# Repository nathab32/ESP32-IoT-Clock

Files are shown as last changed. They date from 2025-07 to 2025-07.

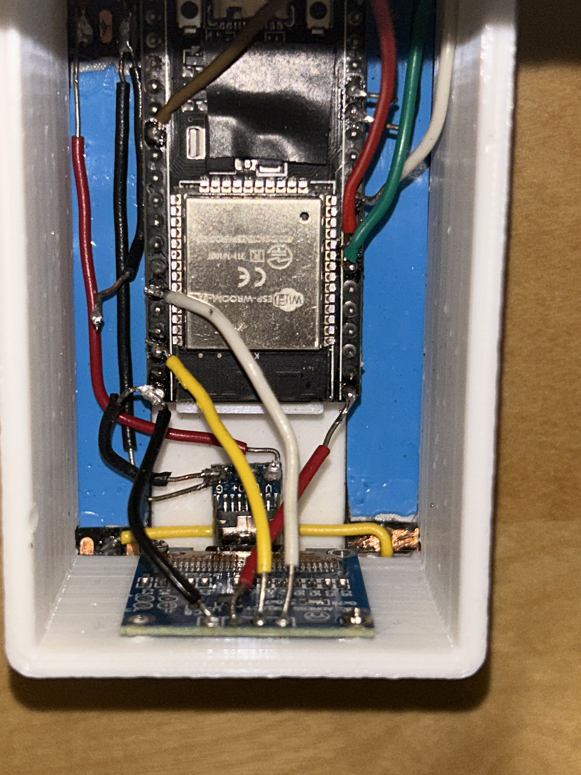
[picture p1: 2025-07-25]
images/wiring/IMG_3684.jpeg

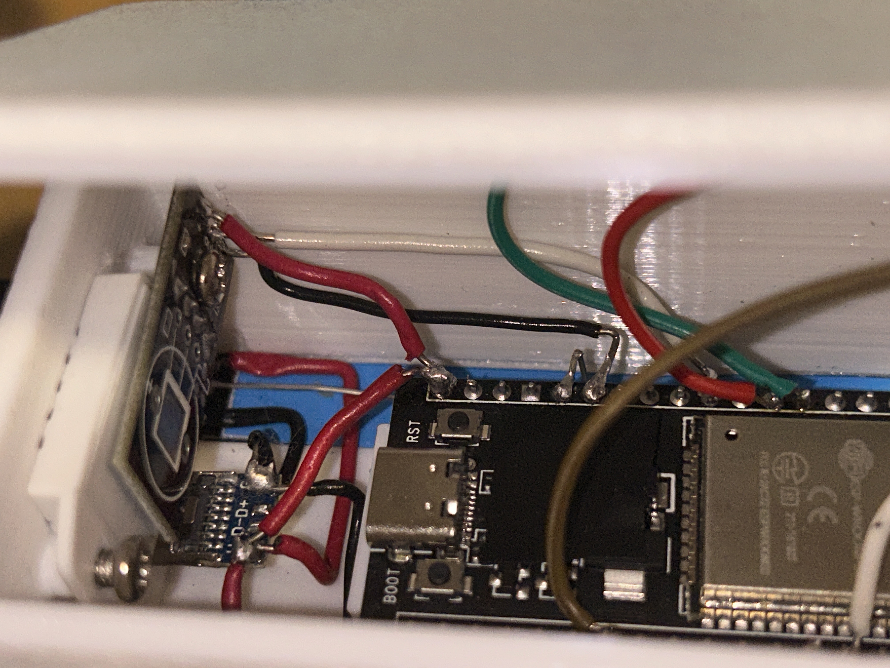
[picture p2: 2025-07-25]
images/wiring/IMG_3688.jpeg

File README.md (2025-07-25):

# ESP32 IoT Clock

## About

Smart clock that has temperature/humidity sensor, LCD, RGB LEDs, 3 capacitive buttons, and a 7.5W USBC charging port. Connects to SinricPro for online functionality. The clock can then connect to Samsung Smartthings through SinricPro, allowing one of the capacitive buttons to control any device connected to your Smartthings account.

The clock should be powered by a wall adapter that can output 5V 3A as the 6x WS2812B LEDs will consume up to 1.8W on max brightness. Combined with the 7.5W charging port, the device can consume up to 9.3W excluding the ESP32's power draw.

### Known Issues

| Issue | Cause | Fix |
|---|---|---|
| Hotter DHT22 reading | Proximity to ESP32 and LEDs | Redesign enclosure with a wall between the sensor and other components, and connect the power to an IO port and only turn it on when necessary |
| Initial light parameters aren't sent to SinricPro | ? | ? |

## Parts

- 1x ESP-WROOM-32 Dev Board Pinout of board I used
- 1x DHT22 Sensor DHT22
- 1x 128x64 I2C OLED OLED Screen
- 2x Female USB-C Port USB-C Port
- 2x 10cm long 30LEDs/m WS2812B strip (or any NeoPixel compatible LED strip)
- 3x 1cm diameter magnets
- Stranded wires
- 3D printed parts (1x Body and Cap, 4x Foot)
- 2x M3\*6, 4x M2\*4

## 3D Printing

STLs can be found in `/3D_Parts`, as well as an F3D file if modifications are necessary. I printed all parts in PLA with a 0.4mm nozzle with fuzzy skin turned on, but most filaments will work and fuzzy.

## SinricPro Setup

1. Create SinricPro account
2. When logged in and on the dashboard, click "Add a new Device"
3. Fill in the device name and description with "Switch", and make sure the Device Type is set to "Switch"
4. Leave everything as default and proceed until you reach the screen with the device ID
5. Once you reach that screen, go to devices on the sidebar and add a "Smart Light Bulb" and a "Temperature Sensor" device using the same method
6. On the Devices screen, there should now be a light, a switch, and a temperature sensor.

## Code

### Prerequisites

- PlatformIO extension in [VS Code](https://marketplace.visualstudio.com/items?itemName=platformio.platformio-ide)
  - ESP32 Platform
  - Libraries
    - SinricPro
    - Adafruit NeoPixel
    - Adafruit SSD1306
    - Adafruit DHT22

### Sensitive.h

1. Download the repository and move it to a safe location on your computer. Open PlatformIO Home and select `Open Project`. Navigate to the folder directory and open it.
2. Open `/src/Sensitive.example.h` and rename it to `Sensitive.h`
3. Add your WiFi credentials to the arrays titled SSID and PASS. You may make the arrays longer if you need more spots.
4. In SinricPro, go to Credentials in the sidebar, then copy the default APP KEY and APP SECRET and fill them in in your `Sensitive.h` file.
5. Now go to Devices, and copy the device IDs and replace them in `Sensitive.h`.

### Test OTA Updates

1. Upload the program to your ESP32 via USB
2. Wait a few seconds for the ESP32 to boot up
3. Check the Modules section in SinricPro. If your ESP32 is online, the IP address should be listed, as well as the version number.
4. Back in VS Code, change the version number in /src/SmartClock.cpp at line 1.
5. Upload the new program OTA by running the command `pio run -t upload --upload-port ip_address`, replacing `ip_address` with the IP address of your ESP32.
6. Once the ESP32 has rebooted and reconnected to WiFi, the new version number you typed in should be reflected in SinricPro, indicating a successful update.

## Assembly

Assembly should be pretty self explanatory. Use double sided tape to secure the ESP32 to the center block in the enclosure. The DHT22 uses the M3 screws, and the OLED screen uses the M2s. The front 7.5W USB-C port needs to have a short between D+ and D- in order to output 7.5W.

The hardest part is wiring and soldering everything together since all of that is done inside of the enclosure. Use the images in `/images/Wiring` to help, as well as the pin numbers on line 30 of `/src/SmartClock.cpp`.

After I soldered everything together, I double checked everything to make sure nothing was wired wrong, then plugged in the back USB-C port while holding it down. Check to make sure everything works (apart from the touch buttons) through the SinricPro website, then secure the USB-C ports down. I used CA glue. Finally, I placed a piece of black electrical tape over my ESP32's power LED since it shone through the top cover of the clock.

## SmartClock.cpp

### Touch Thresholds (Line 36-38)

These values must be set correctly in order for the capacitive touch sensors to properly register inputs. To find the right values, proceed through the following steps.

1. Uncomment the debug block within the `handleScreen()` function and comment out everything within the brackets starting on line 230.
2. Upload the updated code. The OLED screen should now display the live values from the capacitive touch button.
3. For each of the three buttons, note the nominal value when the button is and isn't pressed.
4. Update the threshold for all three buttons by picking a value between the nominal pressed and unpressed values. Higher values will be more sensitive, and lower values are less sensitive.
5. Upload the new thresholds and test each button, adjusting thresholds as needed.

Once the thresholds are set, line 454 can be uncommented to enable the deep sleep function.

### Time Constants (Line 65)

These constants change what server to get the time from, the time zone, and whether or not to account for daylight savings time.

- `ntpServer` can likely be left as is. Search for NTP servers if you need to change it.
- `gmtOffset_sec` adjusts for the timezone you are in. Search up how many hours your timezone is off from GMT, then convert it to seconds and change the value.
- `daylightOffset_sec` will use daylight saving time if set to `3600`, and will not use it if set to `0`.

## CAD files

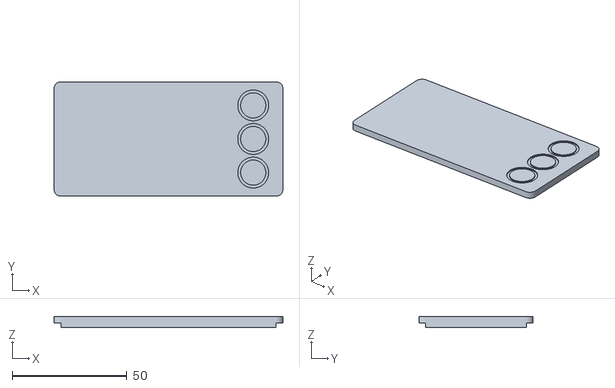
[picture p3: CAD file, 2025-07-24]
3D_Parts/Cap.stl
100.0 x 50.0 x 5.00

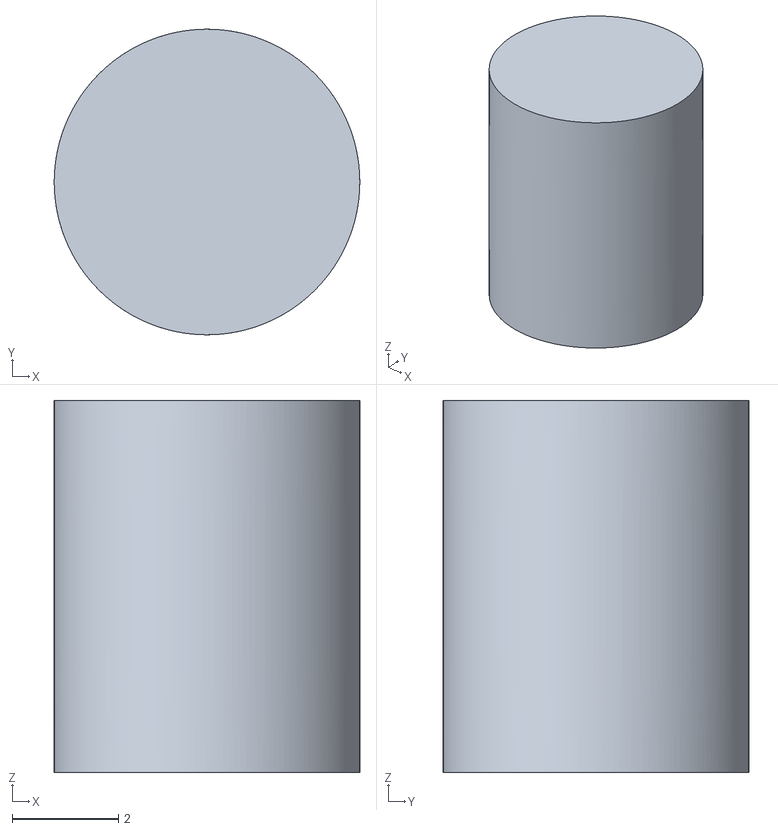
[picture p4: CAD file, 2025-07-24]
3D_Parts/Foot.stl
5.75 x 5.75 x 7.00

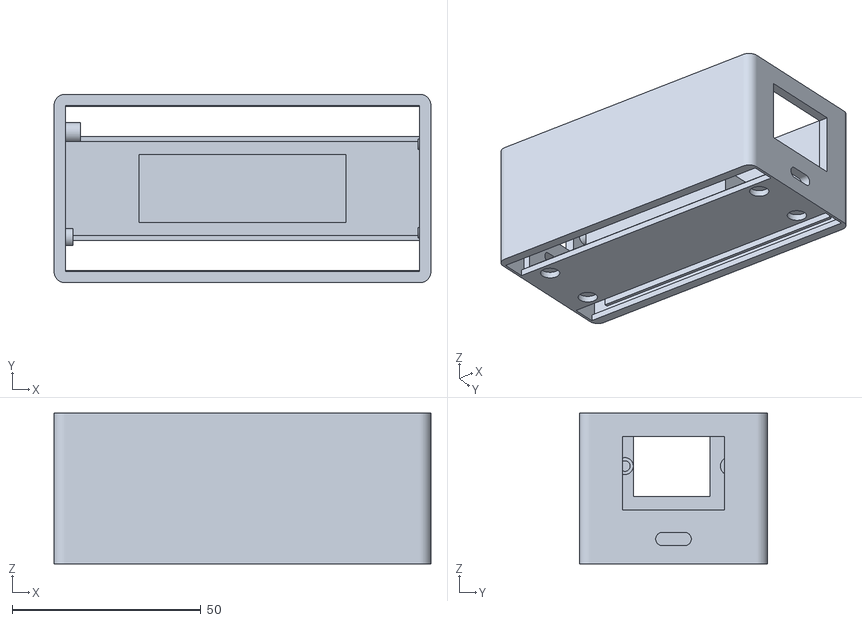
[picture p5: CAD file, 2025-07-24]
3D_Parts/Body.stl
100.0 x 50.0 x 40.0

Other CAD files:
3D_Parts/SmartClock v7.f3d

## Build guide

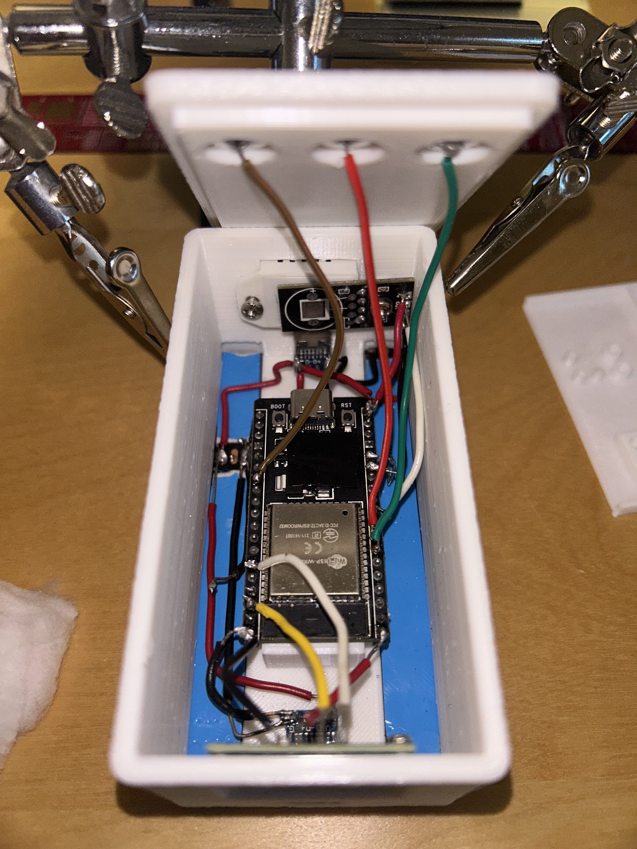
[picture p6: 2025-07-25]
images/wiring/IMG_3683.jpeg

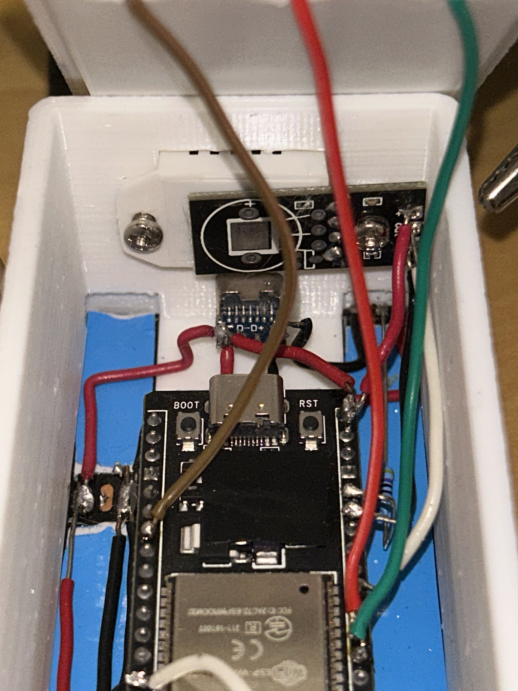
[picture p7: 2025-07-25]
images/wiring/IMG_3685.jpeg

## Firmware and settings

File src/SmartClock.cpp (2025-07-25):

#define FIRMWARE_VERSION "1.0.0"
#include <SinricPro.h>
#include "SinricProTemperaturesensor.h"
#include "SinricProSwitch.h"
#include "SinricProLight.h"

#include <ArduinoOTA.h>
#include <ESPmDNS.h>
#include <WiFiUdp.h>

#include <Arduino.h>

#include <Adafruit_NeoPixel.h>

#include <Adafruit_GFX.h>
#include <Adafruit_SSD1306.h>

#include <DHT.h>

#include "WiFi.h"
#include <WiFiMulti.h>
#include "time.h"

#include "Sensitive.h"

//variables
#define BAUD_RATE 115200       // Change baudrate to your need (used for serial monitor)
#define EVENT_WAIT_TIME 60000  // send event every 60 seconds

//GPIO pins
#define DHT_PIN 26
#define LED_PIN 13
#define CAP_0 4   //for controlling external light
#define CAP_1 33  //for controlling mode of rgbs
#define CAP_2 32  //for turning on and off device
#define TOUCH_THRESHOLD_0 71
#define TOUCH_THRESHOLD_1 80
#define TOUCH_THRESHOLD_2 85

//LED params
const int led = 2;                 // ESP32 Pin to which onboard LED is connected
#define NUM_LEDS 6
Adafruit_NeoPixel leds(NUM_LEDS, LED_PIN, NEO_GRB + NEO_KHZ800);
int brightness = 255;
bool powerStateLED = false;

struct Color {
  uint8_t r;
  uint8_t g;
  uint8_t b;
} ledColor;

enum Effect {
  OFF,
  SOLID,
  GLOWING,
  ALTERNATING,
  RAINBOW
};
Effect effect = OFF;

//oled display
Adafruit_SSD1306 display(128, 64, &Wire, -1);

//time constants
const char *ntpServer = "pool.ntp.org";
const long gmtOffset_sec = -28800; //adjust to time zone (-28800 for PST)
const int daylightOffset_sec = 3600; //adjust for daylight savings time

/* Variable for reading pin status*/
bool switchState = true;
float temp;
float humidity;
float lastTemp;
float lastHumidity;
unsigned long lastEvent = 0;

//devices
DHT dht(DHT_PIN, DHT22);

WiFiMulti wifiMulti;

bool onPowerState(const String &deviceId, bool &state) {
  Serial.printf("Device %s turned %s (via SinricPro) \r\n", deviceId.c_str(), state ? "on" : "off");
  switchState = state;
  return true;  // request handled properly
}

bool onPowerStateLED(const String &deviceId, bool &state) {
  Serial.printf("Device %s turned %s (via SinricPro) \r\n", deviceId.c_str(), state ? "on" : "off");
  powerStateLED = state;
  if (powerStateLED == false) {
    leds.clear();
  } else {
    leds.setBrightness(brightness);
    Serial.print("brightness set to ");
    Serial.println(brightness);
  }
  leds.show();
  return true;  // request handled properly
}

bool onPowerStateTemp(const String &deviceId, bool &state) {
  return true;  // request handled properly
}

bool onBrightness(const String &deviceId, int &val) {
  brightness = map(val, 0, 100, 0, 255);
  // leds.setBrightness(brightness);
  // leds.show();
  return true;
}

bool onAdjustBrightness(const String &deviceId, int brightnessDelta) {
  int percent = map(brightness, 0, 255, 0, 100) + brightnessDelta;
  brightness = map(constrain(percent, 0, 100), 0, 100, 0, 255);
  // leds.setBrightness(map(brightness, 0, 100, 0, 255));
  // leds.show();
  return true;
}

void setColorWithGamma(int red, int green, int blue) {
  // Apply gamma correction to each channel
  ledColor.r = leds.gamma8(red);
  ledColor.g = leds.gamma8(green);
  ledColor.b = leds.gamma8(blue);
}

bool onColor(const String &deviceId, byte &r, byte &g, byte &b) {
  setColorWithGamma(r, g, b);
  // ledColor.r = r;
  // ledColor.g = g;
  // ledColor.b = b;
  return true;
}

Color colorToRGB(int temp) {
  temp /= 100;
  int red;
  if (temp <= 66) red = 255;
  else {
    red = temp - 60;
    red = 329.698727446 * pow(red, -0.1332047592);
    if (red < 0) red = 0;
    if (red > 255) red = 255;
  }

  int green;
  if (temp <= 66) {
    green = 99.4708025861 * log(temp) - 161.1195681661;
  } else {
    green = temp - 60;
    green = 288.1221695283 * pow(green, -0.0755148492);
  }
  if (green < 0) green = 0;
  if (green > 255) green = 255;

  int blue;
  if (temp >= 66) blue = 255;
  else {
    if (temp <= 19) blue = 0;
    else {
      blue = temp - 10;
      blue = 138.5177312231 * log(blue) - 305.0447927307;
      if (blue < 0) blue = 0;
      if (blue > 255) blue = 255;
    }
  }
  setColorWithGamma(red, green, blue);
  return ledColor;
}

bool onColorTemperature(const String &deviceId, int &colorTemperature) {
  colorToRGB(colorTemperature);  // set rgb values from corresponding colortemperauture
  return true;
}

void handleTemperatureSensor() {
  unsigned long actualMillis = millis();
  if (actualMillis - lastEvent < EVENT_WAIT_TIME) return;  //only check every EVENT_WAIT_TIME milliseconds

  temp = dht.readTemperature(true);  // get actual temperature in °F
  humidity = dht.readHumidity();     // get actual humidity

  if (isnan(temp) || isnan(humidity)) {        // reading failed...
    Serial.printf("DHT reading failed!\r\n");  // print error message
    return;                                    // try again next time
  } else {
    Serial.printf("Temp: %2.1f, Humidity: %2.1f%%\r\n", temp, humidity);
  }

  if (temp == lastTemp && humidity == lastHumidity) return;  // if no values changed do nothing...

  SinricProTemperaturesensor &mySensor = SinricPro[TEMP_ID];     // get temperaturesensor device
  bool success = mySensor.sendTemperatureEvent(temp, humidity);  // send event

  // Retry if event fails
  int retries = 0;
  while (!success && retries < 3) {  // Retry up to 3 times
    Serial.printf("Retrying to send event...\r\n");
    success = mySensor.sendTemperatureEvent(temp, humidity);
    retries++;
    delay(500);  // Delay for retry
  }

  if (success) {  // if event was sent successfuly, print temperature and humidity to serial
    Serial.printf("Temperature: %2.1f Celsius\tHumidity: %2.1f%%\r\n", temp, humidity);
  } else {  // if sending event failed, print error message
    Serial.printf("Something went wrong...could not send temp to server!\r\n");
  }

  lastTemp = temp;           // save actual temperature for next compare
  lastHumidity = humidity;   // save actual humidity for next compare
  lastEvent = actualMillis;  // save actual time for next compare
}

void handleScreen() {
  display.setCursor(0, 0);
  display.setTextSize(1);

  // debug block
  // display.print("CAP_0:");
  // display.println(touchRead(CAP_0));
  // display.print("CAP_1:");
  // display.println(touchRead(CAP_1));
  // display.print("CAP_2:");
  // display.println(touchRead(CAP_2));
  // display.print(brightness);

  {
    //temperature
    display.print(temp, 1);
    display.write(0xF7);
    display.print("F");

    //version number
    display.setCursor(49, 0);
    String version = "v" + String(FIRMWARE_VERSION);
    display.print(version);

    //humidity
    display.setCursor(98, 0);
    display.print(humidity, 1);
    display.print("%");

    //line between temp/humid and time
    display.drawFastHLine(0, 10, 127, SSD1306_WHITE);

    //time
    struct tm timeinfo;
    if (!getLocalTime(&timeinfo)) {
      Serial.println("Failed to get time");
    } else {
      display.setCursor(4, 16);
      display.setTextSize(2);
      display.print(&timeinfo, "%a,%b %d");

      display.setCursor(14, 40);
      display.println(&timeinfo, "%T");
    }
  }


  display.display();
  display.clearDisplay();
}

unsigned long previousPress0;
unsigned long previousPress1;

void handleTouchSensors() {
  //button1, 4
  if (touchRead(CAP_0) < TOUCH_THRESHOLD_0 && millis() - previousPress0 > 500) {
    switchState = !switchState;
    // get Switch device back
    SinricProSwitch &mySwitch = SinricPro[SWITCH_ID];
    // send powerstate event
    bool success = mySwitch.sendPowerStateEvent(switchState);  // send the new powerState to SinricPro server
    if (!success) {
      Serial.printf("Something went wrong...could not send switch state to server!\r\n");
    }
    Serial.printf("Device %s turned %s (manually via flashbutton)\r\n", mySwitch.getDeviceId().c_str(), switchState ? "on" : "off");
    previousPress0 = millis();  // update last button press variable
  }


  //button2, 32, led control
  if (touchRead(CAP_1) < TOUCH_THRESHOLD_1 && millis() - previousPress1 > 500) {
    effect = static_cast<Effect>(((int)effect + 1) % 5);

    if (effect == OFF) {
      powerStateLED = false;
      SinricProLight &myLight = SinricPro[LIGHT_ID];
      myLight.sendPowerStateEvent(powerStateLED);
    }
    else if (effect == SOLID) {
      powerStateLED = true;
      SinricProLight &myLight = SinricPro[LIGHT_ID];
      myLight.sendPowerStateEvent(powerStateLED);
    }
    previousPress1 = millis();  // update last button press variable
  }

  //button3, 33, on off
  if (touchRead(CAP_2) < TOUCH_THRESHOLD_2) {
    display.clearDisplay();
    display.setCursor(0, 0);
    display.setTextSize(1);
    int16_t x1, y1;
    uint16_t w, h;
    display.getTextBounds("Sleeping...", 0, 0, &x1, &y1, &w, &h);
    int16_t x = (display.width() - w) / 2;
    int16_t y = (display.height() - h) / 2;
    display.setCursor(x, y);
    display.print("Sleeping...");
    display.display();
    delay(750);
    esp_deep_sleep_start();
  }
}

// setup function for WiFi connection
void setupWiFi() {
  Serial.printf("\r\n[Wifi]: Connecting");

  WiFi.setSleep(false);
  WiFi.setAutoReconnect(true);
  WiFi.mode(WIFI_STA);

  for (int i = 0; i < (sizeof(SSID)/sizeof(SSID[0])); i++) {
    wifiMulti.addAP(SSID[i].c_str(), PASS[i].c_str());
  }


  Serial.println("Connecting Wifi...");
  if (wifiMulti.run() == WL_CONNECTED) {
    Serial.println("");
    Serial.println("WiFi connected");
    Serial.println("IP address: ");
    Serial.println(WiFi.localIP());
    // digitalWrite(led, HIGH);  // turn on led to indicate successful connection
  }

}

// setup function for SinricPro
void setupSinricPro() {
  // add device to SinricPro
  SinricProTemperaturesensor &mySensor = SinricPro[TEMP_ID];

  SinricProSwitch &mySwitch = SinricPro[SWITCH_ID];
  mySwitch.onPowerState(onPowerState);

  SinricProLight &myLight = SinricPro[LIGHT_ID];
  myLight.onPowerState(onPowerStateLED);
  myLight.onBrightness(onBrightness);
  myLight.onAdjustBrightness(onAdjustBrightness);
  myLight.onColor(onColor);
  myLight.onColorTemperature(onColorTemperature);

  // setup SinricPro
  SinricPro.onConnected([]() {
    Serial.printf("Connected to SinricPro\r\n");
  });
  SinricPro.onDisconnected([]() {
    Serial.printf("Disconnected from SinricPro\r\n");
  });
  
  SinricPro.begin(APP_KEY, APP_SECRET);
}

void setupDisplay() {
  if (!display.begin(SSD1306_SWITCHCAPVCC, 0x3C)) {
    // digitalWrite(led, HIGH);
  }
  display.setCursor(0, 0);
  display.setTextColor(WHITE, BLACK);
  display.clearDisplay();
  display.display();
}

void setupLED() {
  ledColor.r = 255;
  ledColor.g = 255;
  ledColor.b = 255;

  leds.begin();
  leds.clear();
  leds.show();
  leds.setBrightness(brightness);

  SinricProLight &myLight = SinricPro[LIGHT_ID];
  myLight.sendColorEvent(ledColor.r, ledColor.g, ledColor.b);
  myLight.sendBrightnessEvent(brightness);
  myLight.sendPowerStateEvent(powerStateLED);
}

void handleLED() {
  if (powerStateLED == false) {
    leds.clear();
    leds.show();
    return;
  }

  int time = millis();

  switch (effect)
  {
    case SOLID:
      {
        leds.fill(leds.Color(ledColor.r, ledColor.g, ledColor.b));
        leds.setBrightness(brightness);
      }
      break;
    case GLOWING:
      {
        float glow = fabs(sin(time / 6000.0 * 2 * 3.14159));
        int mappedBrightness = map((int)(glow * 1000), 0, 1000, 0, brightness);
        leds.setBrightness(mappedBrightness);
        leds.fill(leds.Color(ledColor.r, ledColor.g, ledColor.b));
      } 
      break;
    case ALTERNATING:
      {
        for (int i = leds.numPixels(); i > 0; i--) {
          if (time % 1000 < 500) {
            if (i % 2 == 0) leds.setPixelColor(i-1, leds.Color(ledColor.r, ledColor.g, ledColor.b));
            else leds.setPixelColor(i-1, 0, 0, 0);
          }
          else {
            if (i % 2 == 0) leds.setPixelColor(i-1, 0, 0, 0);
            else leds.setPixelColor(i-1, leds.Color(ledColor.r, ledColor.g, ledColor.b));
          }
        }
      }
      break;
    case RAINBOW:
      {
        // leds.setBrightness(brightness);
        leds.rainbow(map(time % 2000, 0, 1999, 0, 65535), 1, ledColor.r, brightness, true);
      }
      break;
    
    }
  
  leds.show();
}

void setup() {
  // put your setup code here, to run once:
  Serial.begin(BAUD_RATE);
  pinMode(led, OUTPUT);
  setupWiFi();
  // touchSleepWakeUpEnable(CAP_2, TOUCH_THRESHOLD_2);   // uncomment when threshold is set

  //DO NOT CHANGE
  {
    ArduinoOTA
      .onStart([]() {
        String type;
        if (ArduinoOTA.getCommand() == U_FLASH)
          type = "sketch";
        else  // U_SPIFFS
          type = "filesystem";

        // NOTE: if updating SPIFFS this would be the place to unmount SPIFFS using SPIFFS.end()
        Serial.println("Start updating " + type);
      })
      .onEnd([]() {
        Serial.println("\nEnd");
      })
      .onProgress([](unsigned int progress, unsigned int total) {
        Serial.printf("Progress: %u%%\r", (progress / (total / 100)));
      })
      .onError([](ota_error_t error) {
        Serial.printf("Error[%u]: ", error);
        if (error == OTA_AUTH_ERROR) Serial.println("Auth Failed");
        else if (error == OTA_BEGIN_ERROR) Serial.println("Begin Failed");
        else if (error == OTA_CONNECT_ERROR) Serial.println("Connect Failed");
        else if (error == OTA_RECEIVE_ERROR) Serial.println("Receive Failed");
        else if (error == OTA_END_ERROR) Serial.println("End Failed");
      });

    ArduinoOTA.begin();
    for (int i = 0; i < 5000; i += 100) {
      ArduinoOTA.handle();
      delay(100);
    } 
  }

  setupSinricPro();

  dht.begin();

  setupDisplay();

  configTime(gmtOffset_sec, daylightOffset_sec, ntpServer);

  setupLED();
}


void loop() {
  // put your main code here, to run repeatedly:
  SinricPro.handle();
  ArduinoOTA.handle();
  handleTemperatureSensor();
  handleTouchSensors();
  handleScreen();
  handleLED();

  if (wifiMulti.run() != WL_CONNECTED) {
    Serial.println("WiFi not connected!");
  }

  Serial.println(FIRMWARE_VERSION);
}

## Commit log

2025-07-20 clean up comments, add/fix lighting effects
    [SmartClock.cpp]
2025-07-20 refactor color handling to apply gamma correction in setColorWithGamma function, and apply gamma to color conversion
    [SmartClock.cpp]
2025-07-20 change initial state of leds to off, and add initial ota time as safety
2025-07-24 fix brightness control issue
    [SmartClock.cpp]
2025-07-24 Add STLs
    [Body.stl, Cap.stl, Foot.stl]
2025-07-25 Update parts list in README to specify 3D printed parts and additional screws
2025-07-25 add wiring images
2025-07-25 change folder name to 3D_Parts
    [Body.stl, Cap.stl, Foot.stl]
2025-07-25 Add f3d file
    [SmartClock v7.f3d]
2025-07-25 Put functional handleScreen() code in brackets and commented out deep sleep pin by default
